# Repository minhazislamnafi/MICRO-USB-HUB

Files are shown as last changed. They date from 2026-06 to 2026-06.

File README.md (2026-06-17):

# MICRO-USB-HUB






Micro USB HUB

# Specification

* USB HUB
* 1 upstream & 4 downstream
* 4 USB type-C (1 upstream & 3 downstream) and 1 USB type-A
* Chip- Fe1.1s SSOP-28
* dimentions: x x (LxWxH)

# Why you will need this micro usb hub?
Beacuse you definitly need a type-C usb hub if your using a desktop computer. also as its name suggests its very small and compact measures only (50x25x16)mm. So you should build one;)

# Documentation
In this repository, you can find 3D printable STL files file the USB hub enclosure, Garber, and all the other
files to build your own 4-port compact USB HUB. 

# Quick Start

## Requirements

## Components:

* Fe1.1s ssop-28 USB hub IC x1 (https://s.click.aliexpress.com/e/_c3coFDb3)
* 16p Type-C receptical port X4 (https://s.click.aliexpress.com/e/_c3JNhMQz)
* 4p Type-A port x1 (https://s.click.aliexpress.com/e/_c4ryhZZn)
* USBLC6-2SC6 SOT-23-6 x1 (https://s.click.aliexpress.com/e/_c4aL9H4z)
* 0603 resisotr 5.1k x8 (https://s.click.aliexpress.com/e/_c3cSR54l)
* 0603 resistor 12k x1 (https://s.click.aliexpress.com/e/_c3cSR54l)
* 0603 capacitor 10uF x2 (https://s.click.aliexpress.com/e/_c42BS133)
* 0603 capacitor 22pF x2 (https://s.click.aliexpress.com/e/_c42BS133)
* 2016 Crystal oscillator x1 (https://s.click.aliexpress.com/e/_c2QYKExf)

## For detailed parts list and prices follow [BOM](BOM.csv)




# Onshape Full Assembly [LINK](https://cad.onshape.com/documents/72abdd8eb848de8d8be587be/w/fde1524f77307cafb45bef5a/e/de3ea8da0c261ec2d1304d2f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)

## For 3D printing the enclosure 

**You will find the printable .STL file [Here](CAD/Micro%20usb%20hub.stl)**

**Slice the model in center half and print them like this.**



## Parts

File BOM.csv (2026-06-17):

Name | Qty | Footprint | Source | Unit Price | Price (total)
Fe1.1s USB Hub IC | 1 | ssop-28 | [Aliexpress](https://s.click.aliexpress.com/e/_c3coFDb3) | 0.20$ | 0.20$
16p Type-C receptacle port | 4 | 16p | [Aliexpress](https://s.click.aliexpress.com/e/_c3JNhMQz) | 0.52$ | 2.08$
4p Type-A female port | 1 | 4p | [Aliexpress](https://s.click.aliexpress.com/e/_c4ryhZZn) | 0.51$ | 0.51$
USBLC6-2SC6 | 5 | SOT-23-6 | [Aliexpress](https://s.click.aliexpress.com/e/_c4aL9H4z) | 0.13$ | 1.3$
SMD capacitor 10uF | 2 | 0603 | [Aliexpress](https://s.click.aliexpress.com/e/_c42BS133) | 0.008$ | 0.80$
SMD resisotr 5.1k | 8 | 0603 | [Aliexpress](https://s.click.aliexpress.com/e/_c3cSR54l) | 0.0065$ | 0.65$
SMD resistor 12k | 1 | 0603 | [Aliexpress](https://s.click.aliexpress.com/e/_c3cSR54l) | 0.0065$ | 0.65$
SMD capacitor 22pF | 2 | 0603 | [Aliexpress](https://s.click.aliexpress.com/e/_c42BS133) | 0.008$ | 0.80$
Crystal oscillator | 1 | 2016 | [Aliexpress](https://s.click.aliexpress.com/e/_c2QYKExf) | 0.55$ | 1.10$
PCB Fabrication | 5 |  | [JLC PCB](https://jlcpcb.com/quote) | 0.40$ | 2.00$
3D printing | 1 |  | Local vendor | 1.00$ | 1.00$
 |  |  | Total Price(in USD) |  | Around 12.5$(without shiping)

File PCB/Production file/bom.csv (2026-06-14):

Designator | Footprint | Quantity | Value | LCSC Part #
C18, C19 | 0603 | 2 | 10uF
C20, C21 | 0603 | 2 | 22pF
J1, J2, J3, J5 | USB_C_Receptacle_GCT_USB4105-xx-A_16P_TopMnt_Horizontal | 4 | USB_C_Receptacle_USB2.0_16P
J4 | USB_A_TE_292303-7_Horizontal | 1 | USB_A
R1, R2, R3, R4, R5, R6, R7, R8 | 0603 | 8 | 5.1k
R15 | 0603 | 1 | 12K
U1 | SSOP-28_3.9x9.9mm_P0.635mm | 1 | FE1.1s
U2, U3, U4, U5, U6 | SOT-23-6 | 5 | USBLC6-2SC6
Y4 | Crystal_SMD_2016-4Pin_2.0x1.6mm | 1 | 12MHz

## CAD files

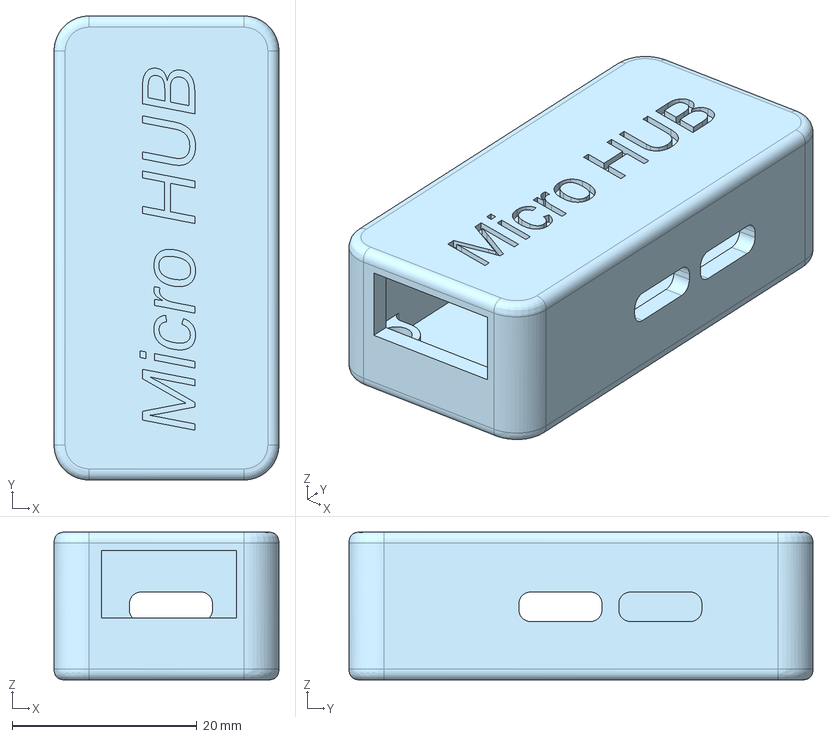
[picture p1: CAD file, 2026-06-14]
CAD/Micro USB hub.step
24.3 x 50.2 x 16.0 mm

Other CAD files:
CAD/Micro usb hub.stl

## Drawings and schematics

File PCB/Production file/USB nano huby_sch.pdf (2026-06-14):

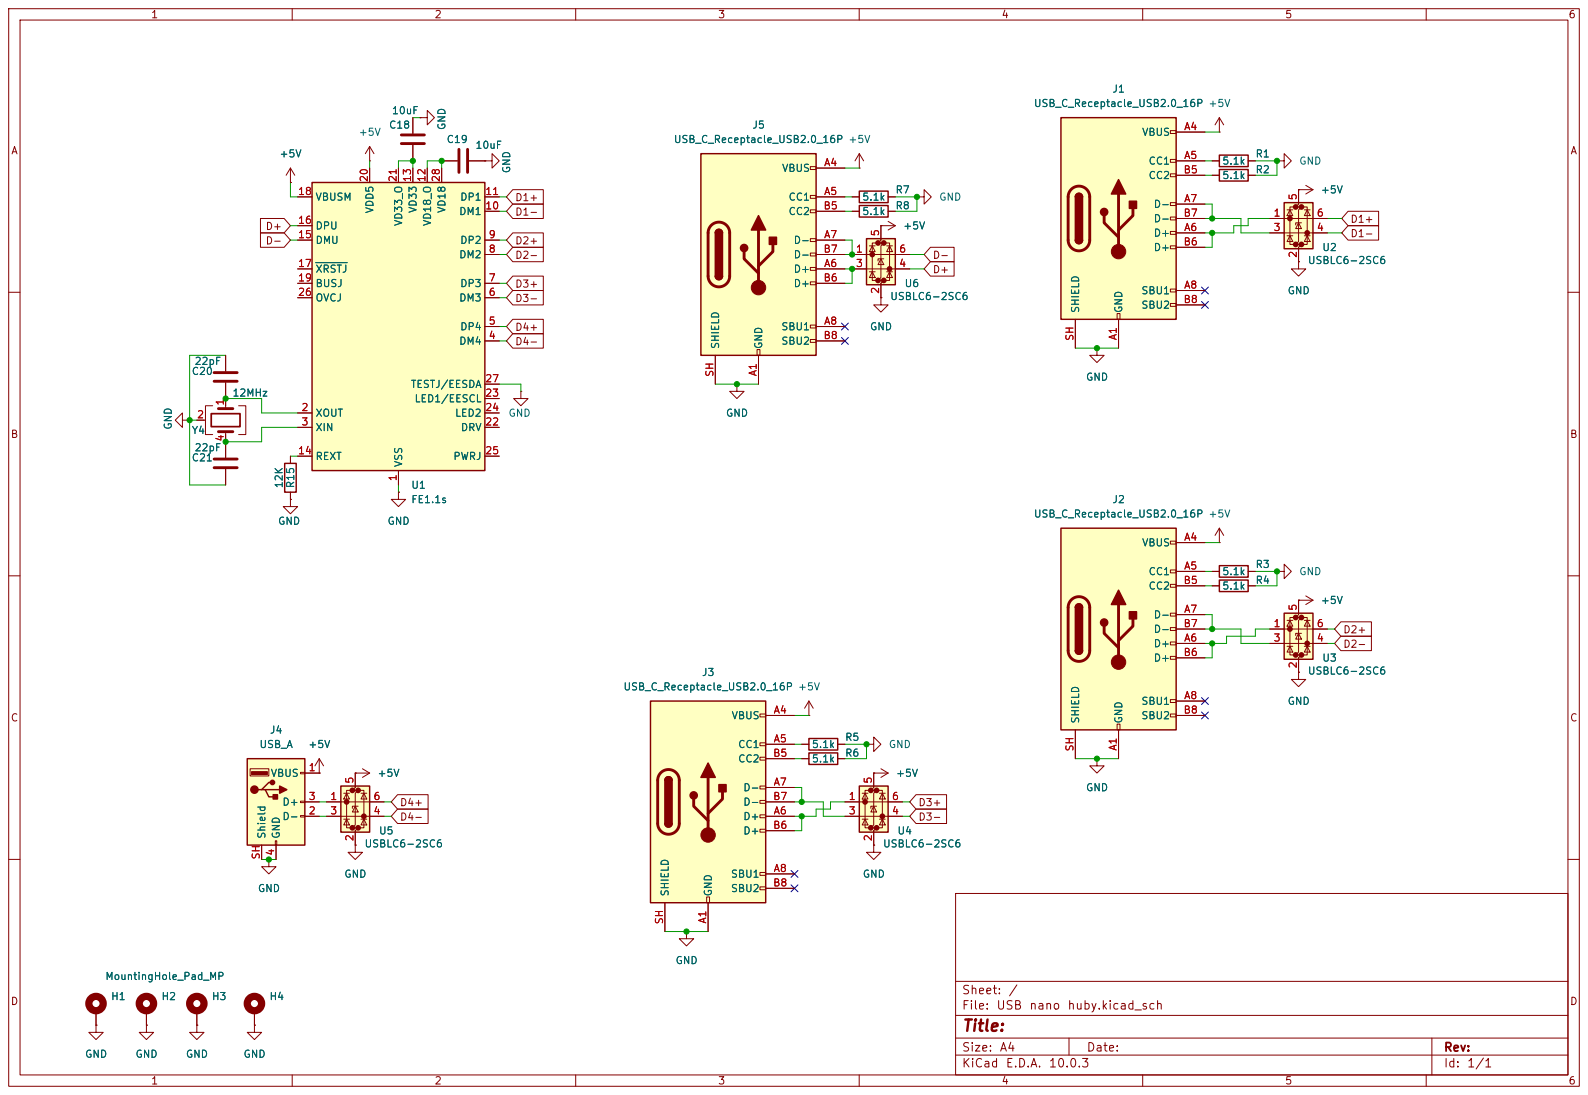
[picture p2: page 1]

Sheet: /
File: USB nano huby.kicad_sch
Title:

Size: A4 | Rev:
KiCad E.D.A. 10.0.3 | Id: 1/1

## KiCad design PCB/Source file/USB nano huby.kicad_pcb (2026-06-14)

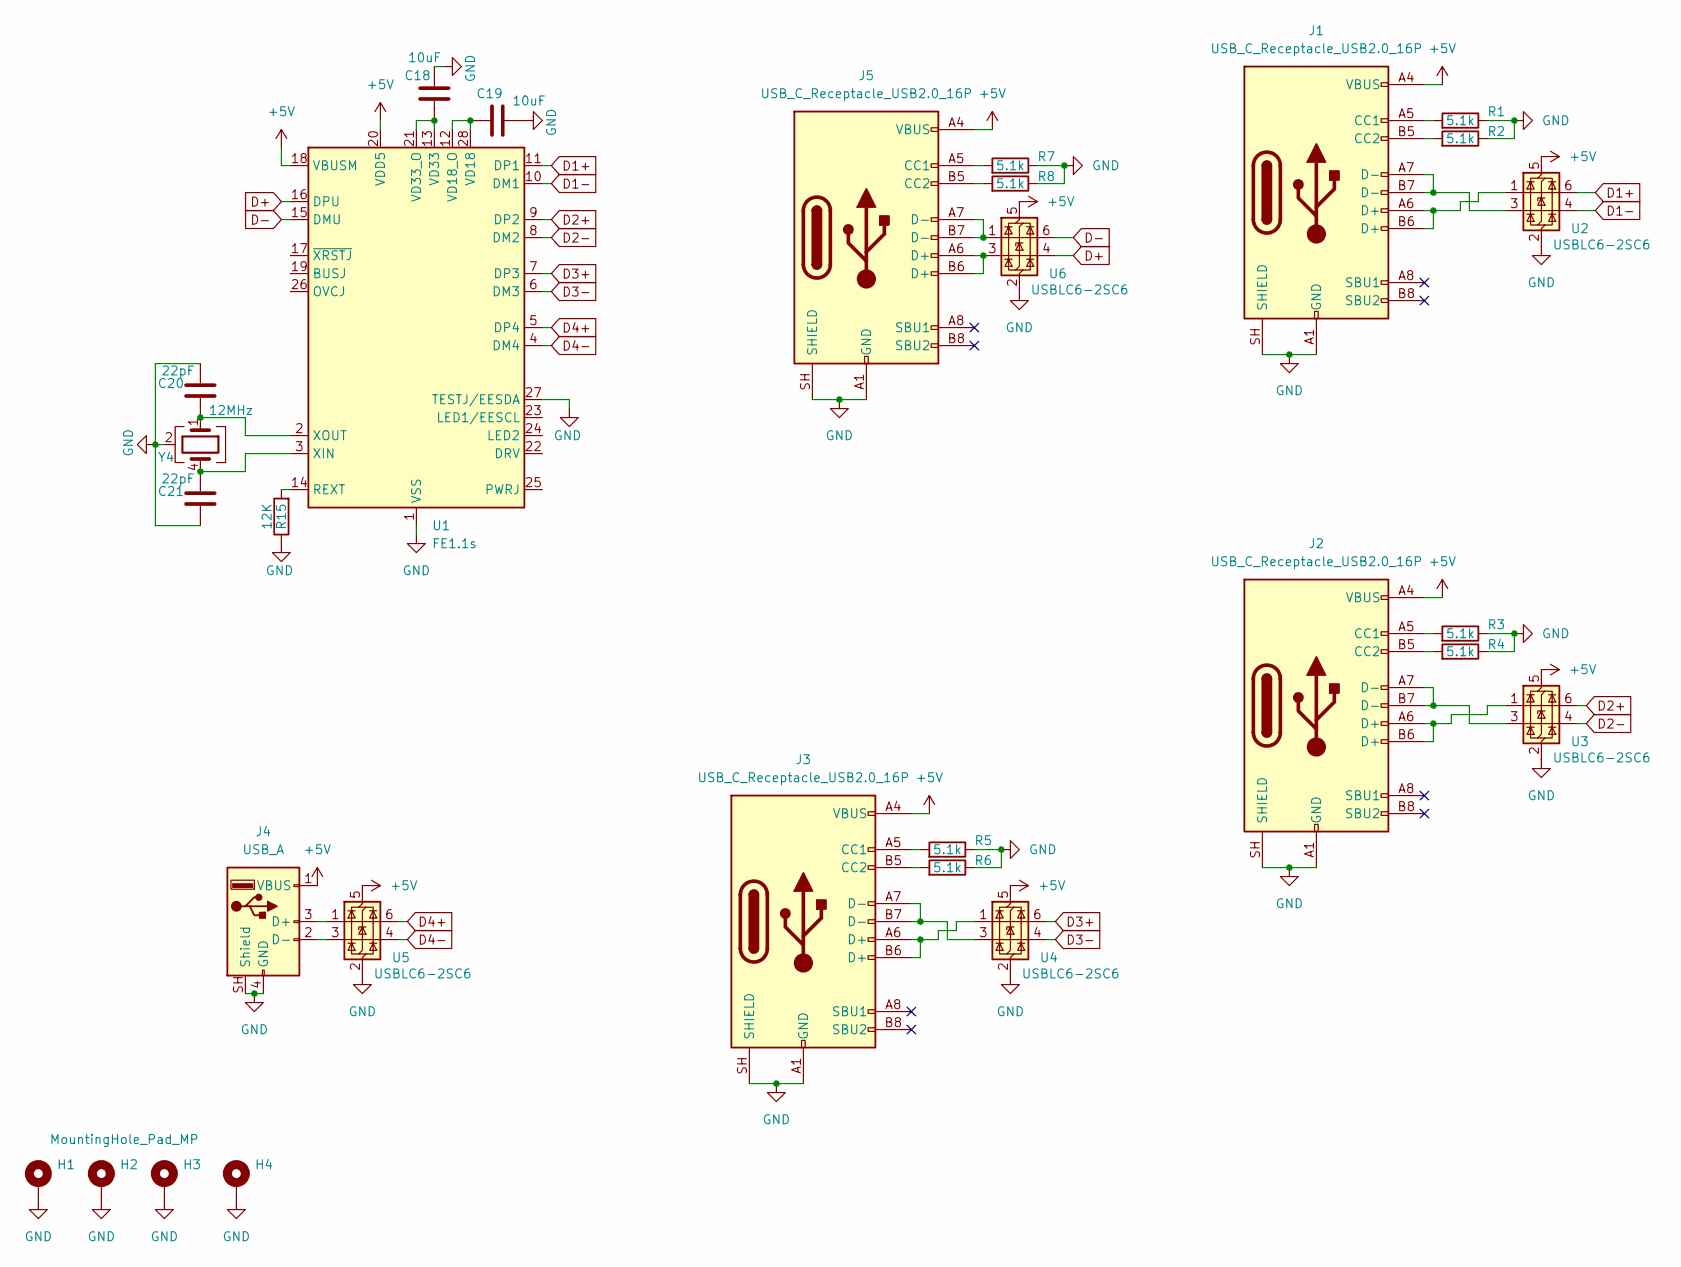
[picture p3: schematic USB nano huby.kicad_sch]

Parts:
C18, C19: 10uF; C_0603_1608Metric
C20, C21: 22pF; C_0603_1608Metric
H1, H2, H3, H4: MountingHole_Pad_MP; MountingHole_2.2mm_M2_DIN965_Pad
J1, J2, J3, J5: USB_C_Receptacle_USB2.0_16P; USB_C_Receptacle_GCT_USB4105-xx-A_16P_TopMnt_Horizontal
J4: USB_A; USB_A_TE_292303-7_Horizontal
R1, R2, R3, R4, R5, R6, R7, R8: 5.1k; R_0603_1608Metric
R15: 12K; R_0603_1608Metric_Pad0.98x0.95mm_HandSolder
U1: FE1.1s; SSOP-28_3.9x9.9mm_P0.635mm
U2, U3, U4, U5, U6: USBLC6-2SC6; SOT-23-6
Y4: 12MHz; Crystal_SMD_2016-4Pin_2.0x1.6mm

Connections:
+5V: J1.A4 (VBUS), J1.A9 (VBUS), J1.B4 (VBUS), J1.B9 (VBUS), J2.A4 (VBUS), J2.A9 (VBUS), J2.B4 (VBUS), J2.B9 (VBUS), J3.A4 (VBUS), J3.A9 (VBUS), J3.B4 (VBUS), J3.B9 (VBUS), J4.1 (VBUS), J5.A4 (VBUS), J5.A9 (VBUS), J5.B4 (VBUS), J5.B9 (VBUS), U1.18 (VBUSM), U1.20 (VDD5), U2.5 (VBUS), U3.5 (VBUS), U4.5 (VBUS), U5.5 (VBUS), U6.5 (VBUS)
D1+: U1.11 (DP1), U2.6 (I/O1)
D1-: U1.10 (DM1), U2.4 (I/O2)
D2+: U1.9 (DP2), U3.6 (I/O1)
D2-: U1.8 (DM2), U3.4 (I/O2)
D3+: U1.7 (DP3), U4.6 (I/O1)
D3-: U1.6 (DM3), U4.4 (I/O2)
D4+: U1.5 (DP4), U5.6 (I/O1)
D4-: U1.4 (DM4), U5.4 (I/O2)
D+: U1.16 (DPU), U6.4 (I/O2)
D-: U1.15 (DMU), U6.6 (I/O1)
GND: C18.1, C19.1, C20.1, C21.2, H1.MP, H2.MP, H3.MP, H4.MP, J1.A1 (GND), J1.A12 (GND), J1.B1 (GND), J1.B12 (GND), J1.SH (SHIELD), J2.A1 (GND), J2.A12 (GND), J2.B1 (GND), J2.B12 (GND), J2.SH (SHIELD), J3.A1 (GND), J3.A12 (GND), J3.B1 (GND), J3.B12 (GND), J3.SH (SHIELD), J4.4 (GND), J4.SH (Shield), J5.A1 (GND), J5.A12 (GND), J5.B1 (GND), J5.B12 (GND), J5.SH (SHIELD), R1.2, R2.2, R3.2, R4.2, R5.2, R6.2, R7.2, R8.2, R15.1, U1.1 (VSS), U1.27 (TESTJ/EESDA), U2.2 (GND), U3.2 (GND), U4.2 (GND), U5.2 (GND), U6.2 (GND), Y4.2 (G), Y4.3 (G)
unnamed: J1.A5 (CC1), R1.1
unnamed: J1.B5 (CC2), R2.1
unnamed: J1.A6 (D+), J1.B6 (D+), U2.1 (I/O1)
unnamed: J1.A7 (D-), J1.B7 (D-), U2.3 (I/O2)
unnamed: J2.A5 (CC1), R3.1
unnamed: J2.B5 (CC2), R4.1
unnamed: J2.A6 (D+), J2.B6 (D+), U3.1 (I/O1)
unnamed: J2.A7 (D-), J2.B7 (D-), U3.3 (I/O2)
unnamed: J3.A5 (CC1), R5.1
unnamed: J3.B5 (CC2), R6.1
unnamed: J3.A6 (D+), J3.B6 (D+), U4.1 (I/O1)
unnamed: J3.A7 (D-), J3.B7 (D-), U4.3 (I/O2)
unnamed: J4.3 (D+), U5.1 (I/O1)
unnamed: J4.2 (D-), U5.3 (I/O2)
unnamed: J5.A5 (CC1), R7.1
unnamed: J5.B5 (CC2), R8.1
unnamed: J5.A6 (D+), J5.B6 (D+), U6.3 (I/O2)
unnamed: J5.A7 (D-), J5.B7 (D-), U6.1 (I/O1)
unnamed: R15.2, U1.14 (REXT)
unnamed: C19.2, U1.12 (VD18_O), U1.28 (VD18)
unnamed: C18.2, U1.13 (VD33), U1.21 (VD33_O)
unnamed: C21.1, U1.3 (XIN), Y4.4
unnamed: C20.2, U1.2 (XOUT), Y4.1

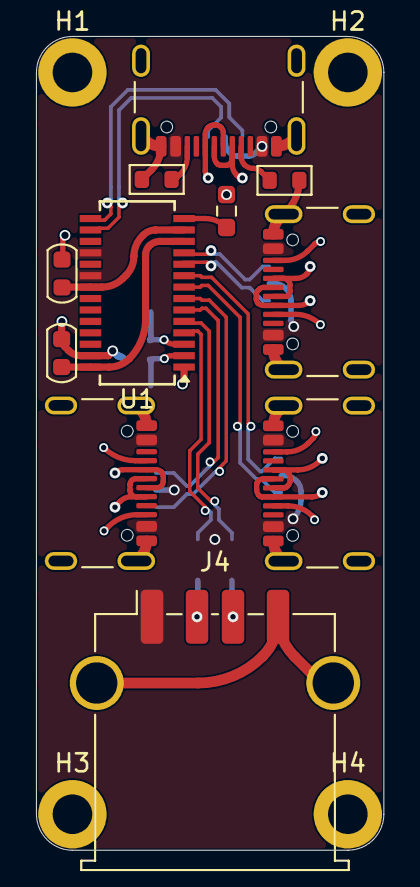
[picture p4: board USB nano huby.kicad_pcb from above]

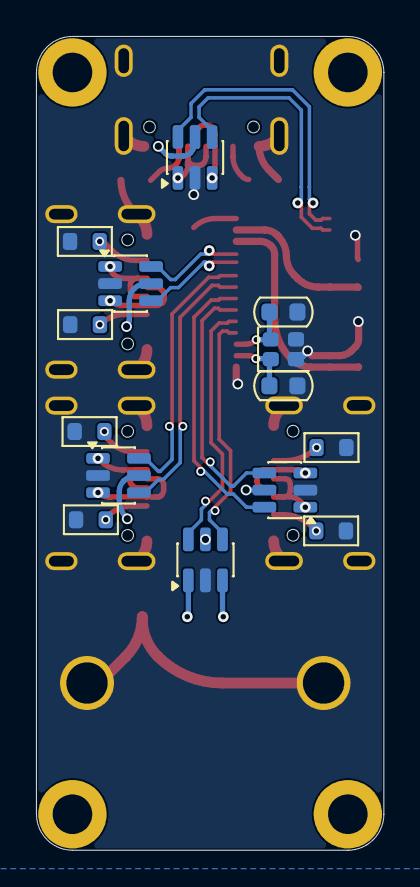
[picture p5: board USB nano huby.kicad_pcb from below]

Board: 2 copper layers, 19.3 x 45.2 mm, 29 parts (14 on the bottom side), 35 nets.

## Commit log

2026-06-17 Fix typos and update total price in BOM.csv
    [BOM.csv]
2026-06-17 Update README with 3D printing instructions and links
    Added section for 3D printing the enclosure and updated links.

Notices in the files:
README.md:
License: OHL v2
